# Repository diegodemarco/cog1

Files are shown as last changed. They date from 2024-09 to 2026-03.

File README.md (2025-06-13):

# cog1
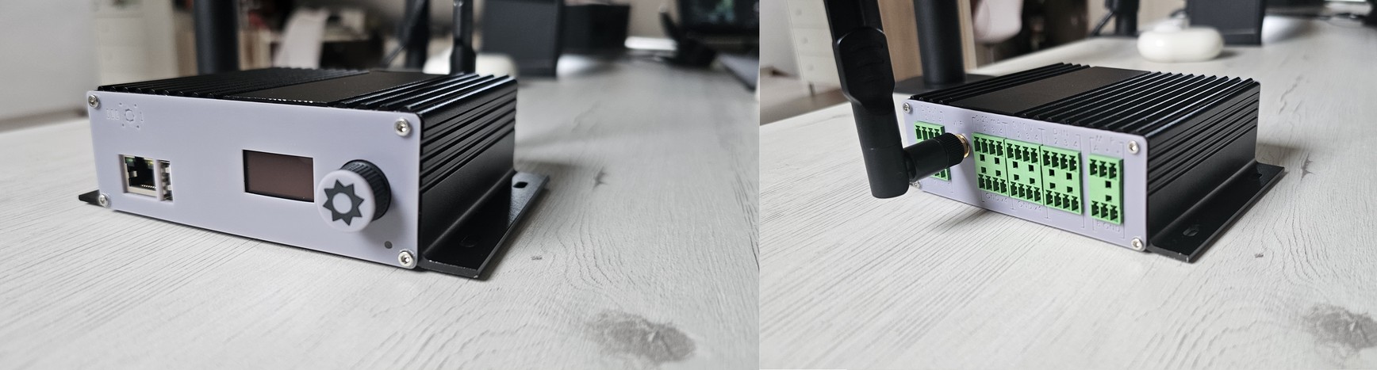
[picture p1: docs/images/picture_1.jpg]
cog1 front and back as built


## What is cog1?
cog1 is an open-source industrial IoT gateway (hardware and software) built as a motherboard hosting an [Orange Pi Zero 3](http://www.orangepi.org/html/hardWare/computerAndMicrocontrollers/details/Orange-Pi-Zero-3.html) linux SBC (Wiki [here](http://www.orangepi.org/orangepiwiki/index.php/Orange_Pi_Zero_3)).
- The motherboard was designed using [KiCad](https://www.kicad.org/).
- Its software uses the [.net core framework](https://dotnet.microsoft.com/) (currently at version 8) to provide the services running in the hardware, as well as the back-end web services for the UI.
- It also hosts the user interface (console), which is written  in [Angular](https://angular.dev/), based on the [Core-UI admin template](https://coreui.io/product/free-angular-admin-template/).
- In essence, it's a fully self-contained IoT gateway capable of interfacing with sensors and actuators directly, designed to process data, make local decisions, and communicate with external cloud services if needed.

### Features

#### Hardware
The cog1 platform currently supports:
- Powered by any DC supply from 12 to 24 VDC.
- Four digital inputs (isolated, using two [ISO 1212](https://www.ti.com/lit/ds/symlink/iso1212.pdf) chips from TI).
- Four digital outputs (relays, varistor-protected).
- Four analog voltage inputs (0-10 V, non-isolated), protected up to 48 VDC. The ADC is an [ADC128D818](https://www.ti.com/lit/ds/symlink/adc128d818.pdf) chip from TI.
- Four analog current inputs (0-20 mA, non isolated), protected up to 100 mA. Uses the same [ADC128D818](https://www.ti.com/lit/ds/symlink/adc128d818.pdf) chip as the voltage inputs.
- One RS-485 port (tested from 9600 to 115200 bauds). Support for Modbus RTU is already built on top of this.
- Battery-backed RTC.
- A simple but extensible user interface with a small OLED display and a rotary encoder + pushbutton.
- All connectivity inherited from the Orange Pi Zero 3 SBC
  - 1 Gb Ethernet
  - 2.4 + 5.8 GHz WiFi
  - Bluetooth 5
  - A front USB port (USB 2.0)

#### Software
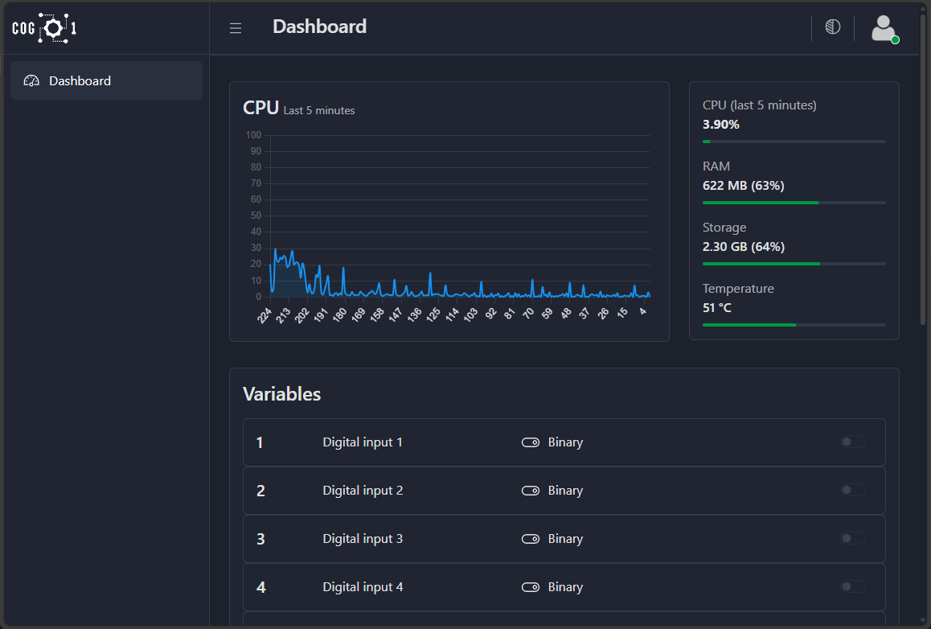
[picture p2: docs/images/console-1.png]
cog1 admin console

The current software is rather basic, but includes everything needed to fully test the hardware. Additionally, the software already has the correct "architecture", i.e. it is designed as a linux service file that can be started, stopped, etc., and communicates with the hardware through a low-level i/o library created with native code (plain old C).

The front-end (console) is written in Angular, based on the [Core-UI admin template](https://coreui.io/product/free-angular-admin-template/), and it communicates with the back-end via web-services, which are already integrated in such a way that creating new controllers/endpoints and consuming them from the front-end is really simple. 

The following features are already implemented:
- Internal variables are fully supported. These match the actual hardware of the cog1.
- External variables can be defined as well, based on Modbus registers.
- Both Modbus RTU and Modbus TCP are supported, allowing reading and writing the most common types of registers in a variety of data types.
- Variables can be defined to be "polled" automatically. For variables bound to Modbus registers, this means that the respective registers are polled via RTU or TCP as needed.
- Writeable variables can be controlled/modified from the dashboard.
- Writeable variables bound to Modbus registers also trigger the respective write operations through RTU or TCP, which can be done from the dashboard.

The plan is to continue developing the software so that it can:
- Provide data-extraction web services.
- Communicate with external cloud services via MQTT or any other protocol that could be relevant.
- Allow running javascript code using [Jint](https://github.com/sebastienros/jint) to make it possible to compute complex variables, do edge data-processing, etc.
- Update the console UI to allow further management of all avaible functionality, as it grows over time.

### Hardware
#### PCB
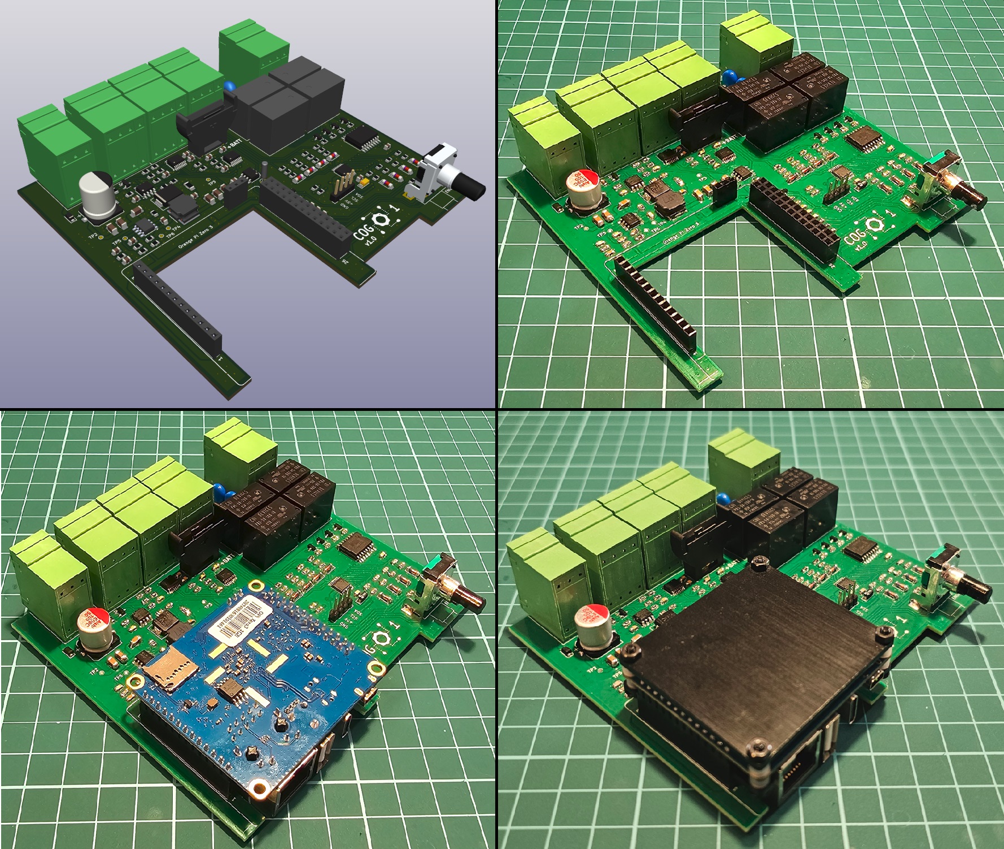
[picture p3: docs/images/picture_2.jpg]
cog1 PCB as rendered by KiCad


The PCB has been designed using KiCad. It contains everything needed, including a 3D render. All components can be hand-soldered, but a few (essentially the AOZ regulator, the ADC, and the digital input isolators) require a bit of skills, as they are SSOP components. 

All capacitors, resistors, etc. are 0805 or bigger, so they can be hand-soldered with little effort. The PCB contains all necessary headers to allow the Orange Pi Zero 3 to be plugged in, inverted.

All components can be found in the usual marketplaces (DigiKey, Mouser, etc.). I strongly advice not using unreliable (i.e. unrealistically cheap) sources for the components, especially the chips, as there is a large market of fake chips that either don't work, or even worse, work erratically.

#### Enclosure
The enclosure for the cog1 is a rather standard extruded-aluminum case, which can be found online for a few bucks. However, as a 3D printing enthusiast, I ended up designing and printing everything necessary to complete the enclosure:
- Front cover
- Back cover
- Knob

All designs, done in SolidWorks, are included in this project. I have printed everything with an Elegoo Mars 3 Pro (resin), and expect that all parts would print well on any resin 3D printer. I have not tried to print this on a filament printer, as I believe the quality would not be good enough. When printed in resin, all parts really look production-grade if the proper resin is used.

### Software
#### Main back-end code
The main code of the cog1 platform is a .net core application that contains all the necessary components (web services and general logic) to keep the cog1 working. The current version is relatively basic, and only contains those features needed to test the hardware. A web service is in place to provide basic status of the cog1, which is currently used to test the overall reliability of the hardware. All hardware functions have been tested with this software.

This is by far the area that needs the most effort, so that the cog1 can be turned into a fully-functional gateway.

#### Native back-end code
There are a few small portions of the software written in plan old C, and compiled directly in the SBC:
- A low-level i/o library that deals with digital and analog i/o, display, etc.
- A small "logo" application (configured as a service that starts early in the Linux boot process) to display the cog1 logo while the cog1 is booting.

Everything else is c#, so there's no low-level really in the c# code. 

#### Front-end code
The front-end (console) is written in Angular, based on the [Core-UI admin template](https://coreui.io/product/free-angular-admin-template/), and it communicates with the back-end via web-services, which are already integrated in such a way that creating new controllers/endpoints and consuming them from the front-end is really simple. While the functionality is relatively limited at the moment, the front-end contains all the necessary building-blocks to be extended easily:
- It communicates with the back-end via web-services, with proxies created using [swagger-typescript-api](https://github.com/acacode/swagger-typescript-api). This makes it very simple to create new controllers and endpoints in the back-end andthen use them in the front-end with full type-checking and code insight.
- It handles authentication with the back-end.
- It fully supports loading literals (in the language of the user) from the back-end, before the application starts.

## Getting started
### Building the hardware
The KiCad project included in the pcb folder contains everything needed to manufacture the pcb. For all prototypes, the pcb was ordered to PCBWay, and then all components were soldered manually. When soldering, I strongly advise mounting the switching power supply first, veryfying the 5V are steady and noiseless, and then mount everything else. This is to prevent blowing up anything if the switching power supply was not mounted correctly.

### Installing the software
I'll write a tutorial for this ASAP, but it's pretty straightforward.

## Current status
### What's done
### What's missing

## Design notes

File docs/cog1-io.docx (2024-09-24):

Outputs:

Function | GPIO / PIN | Comments

Front
Led – Heartbeat | 73 / 7
Encoder button | 75 / 12 (isr) | Internal pullup is used (4.7K ohms)
Encoder A | 72 / 15 (isr) | Internal pullup is used (4.7K ohms)
Encoder B | 231 / 19 (isr) | Internal pullup is used (4.7K ohms)
Conn - 485-A | none (UART.5)
Conn - 485-B | none (UART.5)
WiFi-antenna | none

Back
Power + | none
Power - | none
SSR1 + Common | none (PCF8574)
SSR2 + Common | none (PCF8574)
SSR3 + Common | none (PCF8574)
SSR4 + Common | none (PCF8574)
0-20-1 + Common | none (ADS1115-1)
0-20-2 + Common | none (ADS1115-1)
0-20-3 + Common | none (ADS1115-1)
0-20-4 + Common | none (ADS1115-1)
AN1 + Common | none (ADS1115-2)
AN2 + Common | none (ADS1115-2)
AN3 + Common | none (ADS1115-2)
AN4 + Common | none (ADS1115-2)
DI1 + Common | 74 / 26 (isr) | Internal pullup is used (4.7K ohms)
DI2 + Common | 233 / 24 (isr) | Internal pullup is used (4.7K ohms)
DI3 + Common | 230 / 23 (isr) | Internal pullup is used (4.7K ohms)
DI4 + Common | 232 / 21 (isr) | Internal pullup is used (4.7K ohms)

Connectors – Front

SMA (Wi-Fi)

Connectors – Back

Power + 485 (2x3)

TOP: VCC, 485A, 485B

Bottom: GND, GND, GND

0-20mA (2x 4)

TOP: AA1, AA2, AA3, AA4

Bottom: GND, GND, GND, GND

0-10V (2x 4)

TOP: AV1, AV2, AV3, AV4

Bottom: GND, GND, GND, GND

DIGITAL IN (2x 4)

TOP: DI1+, DI2+, DI3+, DI4+

Bottom: DI1-, DI2-, DI3-, DI4-

DIGITAL OUT (2x 4)

TOP: DO1A, DO2A, DO3A, DO4A

Bottom: DO1B, DO2B, DO3B, DO4B

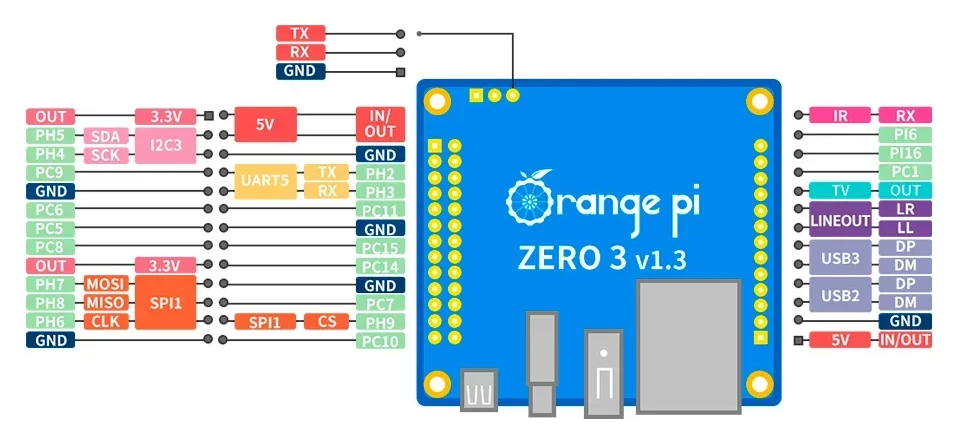
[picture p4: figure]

+------+-----+----------+--------+---+ H616 +---+--------+----------+-----+------+

| GPIO | wPi | Name | Mode | V | Physical | V | Mode | Name | wPi | GPIO |

+------+-----+----------+--------+---+----++----+---+--------+----------+-----+------+

| | | 3.3V | | | 1 || 2 | | | 5V | | |

| 229 | 0 | SDA.3 | ALT5 | 0 | 3 || 4 | | | 5V | | |

| 228 | 1 | SCL.3 | ALT5 | 0 | 5 || 6 | | | GND | | |

| 73 | 2 | PC9 | OUT | 0 | 7 || 8 | 0 | OFF | TXD.5 | 3 | 226 |

| | | GND | | | 9 || 10 | 0 | OFF | RXD.5 | 4 | 227 |

| 70 | 5 | PC6 | OUT | 0 | 11 || 12 | 0 | OFF | PC11 | 6 | 75 |

| 69 | 7 | PC5 | ALT5 | 0 | 13 || 14 | | | GND | | |

| 72 | 8 | PC8 | OFF | 0 | 15 || 16 | 0 | OFF | PC15 | 9 | 79 |

| | | 3.3V | | | 17 || 18 | 0 | OFF | PC14 | 10 | 78 |

| 231 | 11 | MOSI.1 | OFF | 0 | 19 || 20 | | | GND | | |

| 232 | 12 | MISO.1 | OFF | 0 | 21 || 22 | 0 | OFF | PC7 | 13 | 71 |

| 230 | 14 | SCLK.1 | OFF | 0 | 23 || 24 | 0 | OFF | CE.1 | 15 | 233 |

| | | GND | | | 25 || 26 | 0 | OFF | PC10 | 16 | 74 |

| 65 | 17 | PC1 | OFF | 0 | 27 || 28 | | | | | |

| 272 | 18 | PI16 | ALT2 | 0 | 29 || 30 | | | | | |

| 262 | 19 | PI6 | OFF | 0 | 31 || 32 | | | | | |

| 234 | 20 | PH10 | ALT3 | 0 | 33 || 34 | | | | | |

+------+-----+----------+--------+---+----++----+---+--------+----------+-----+------+

| GPIO | wPi | Name | Mode | V | Physical | V | Mode | Name | wPi | GPIO |

+------+-----+----------+--------+---+ H616 +---+--------+----------+-----+------+

Display screens

123456789012345678901

0 STATUS

1 ---------------------

2 Date 2024-07-23 23:59

3 WiFi 192.192.192.192

4 Eth 192.192.192.192

5 Temp 44ºC/92ºF

6 CPU (1 min) 1.8%

7 Firmware 1.0.0.0

123456789012345678901

0 D-IO IN OUT

1 ---------------------

2

3 1 (--) (--)

4 2 (--) (--)

5 3 (--) (--)

6 4 (--) (--)

7

123456789012345678901

0 A-IN V mA

1 ---------------------

2

3 1 0.00 0.00

4 2 0.00 0.00

5 3 0.00 0.00

6 4 0.00 0.00

7

123456789012345678901

0 Wi-Fi

1 ---------------------

2 Status

3 SSID Los De Marco

4 IP 192.192.192.192

5 Band 8153 MHz

6 RSSI -58 dBm

7

123456789012345678901

0 Ethernet

1 ---------------------

2 IP 192.192.192.192

3

4

5

6

7

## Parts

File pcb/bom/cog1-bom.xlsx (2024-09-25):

Id | Designator | Footprint | Quantity | Designation
34 | R58 | R_0805_2012Metric | 1 | 1.2K 1%
7 | C21,C4,C20,C5,C14,C3,C1,C18,C6 | C_0805_2012Metric | 9 | 100nF
19 | R7,R3,R2 | R_0805_2012Metric | 3 | 100R
20 | C7 | CP_Elec_10x12.6 | 1 | 100uF 50V
4 | R43,R46,R8,R47,R1,R39,R37,R4,R36,R13,R38 | R_0805_2012Metric | 11 | 10K
16 | R41,R31,R28,R10,R34 | R_0805_2012Metric | 5 | 10K 1%
21 | C26,C23,C24,C25,C16 | C_0805_2012Metric | 5 | 10nF
35 | R59 | R_0815_2038Metric_Pad1.20x4.05mm_HandSolder | 1 | 10R 1/2W
13 | C10,C9,C8 | C_1206_3216Metric_Pad1.33x1.80mm_HandSolder | 3 | 10uF 50V
26 | C2 | C_0805_2012Metric | 1 | 10uF 6.3V
22 | R57,R44,R45 | R_0805_2012Metric | 3 | 1K
29 | C22 | CP_EIA-3216-10_Kemet-I_Pad1.58x1.35mm_HandSolder | 1 | 1uF
32 | R56 | R_0805_2012Metric | 1 | 255R
25 | R33,R27,R30,R40 | R_0805_2012Metric | 4 | 255R 1%
3 | R21,R18,R24,R17 | R_0805_2012Metric | 4 | 30.1K 1%
33 | Y1 | Crystal_C26-LF_D2.1mm_L6.5mm_Vertical | 1 | 32.768 KHz
42 | C19 | C_0805_2012Metric | 1 | 330pF 50V
2 | R14,R22,R25,R15,R19 | R_0805_2012Metric | 5 | 330R
14 | R11 | R_0805_2012Metric | 1 | 47K
27 | C11,C13,C12 | C_1206_3216Metric_Pad1.33x1.80mm_HandSolder | 3 | 47uF 10V
43 | R9 | R_0805_2012Metric | 1 | 52K 1%
1 | R49,R48,R5,R6 | R_0805_2012Metric | 4 | 560R
41 | C15 | C_0805_2012Metric | 1 | 56pF
47 | C17 | C_0805_2012Metric | 1 | 820pF
40 | R12 | R_0805_2012Metric | 1 | 82K
12 | R29,R32,R26,R23,R35,R16,R20,R42 | R_0805_2012Metric | 8 | 9.53K 1%
46 | U12 | TSSOP-16_4.4x5mm_P0.65mm | 1 | ADC128D818
37 | U5 | AOZ1284PI | 1 | AOZ1284PI
24 | D3 | D_SMC | 1 | B560C-13-F
18 | RV1,RV2,RV3,RV4 | RV_Disc_D7mm_W4.5mm_P5mm | 4 | B72207S0301K103
9 | Q2,Q3,Q4,Q1,Q5 | SOT-23 | 5 | BC807
39 | BATT1 | BH-50B-1 | 1 | BH-50B-1
28 | J1 | PinHeader_1x04_P2.54mm_Vertical | 1 | Conn_01x04_Pin
49 | LED1 | LED_0805_2012Metric_Pad1.15x1.40mm_HandSolder | 1 | INL-3AW30
36 | U2,U4 | SSOP-16_3.9x4.9mm_P0.635mm | 2 | ISO1212
48 | D14,D2,D15,D13 | D_MiniMELF | 4 | LL4148
38 | U10 | SOIC-8_3.9x4.9mm_P1.27mm | 1 | MAX13487E
6 | U$1 | OPI-ZERO-3 | 1 | OPI-ZERO-3
45 | U3 | SOIC-16W_7.5x10.3mm_P1.27mm | 1 | PCA8574D
44 | U1 | SOIC-8_3.9x4.9mm_P1.27mm | 1 | PCF8523T
17 | ENC1 | BOURNS_PEC_HORZ_20 | 1 | PEC12R-2120F-S0012
5 | K1,K3,K4,K2 | PR5-5V-200-1A | 4 | PR5-5V-200-1A
30 | D12 | SOT-23-3 | 1 | SM712
10 | L1 | Bourns_SRN8040TA | 1 | SRN8040TA-4R7M
11 | D1 | D_SOD-123F | 1 | SS2040LL_R1_00001
23 | TP5,TP2,TP3,TP6,TP1,TP4 | TestPoint_Pad_D1.0mm | 6 | TestPoint
31 | CN1 | VL0631510000G | 1 | VL0631510000G
15 | CN3,CN4,CN2,CN5 | VL0831510000G | 4 | VL0831510000G
8 | D11,D7,D9,D8,D4,D10,D6,D5 | D_MiniMELF | 8 | ZMM3.0

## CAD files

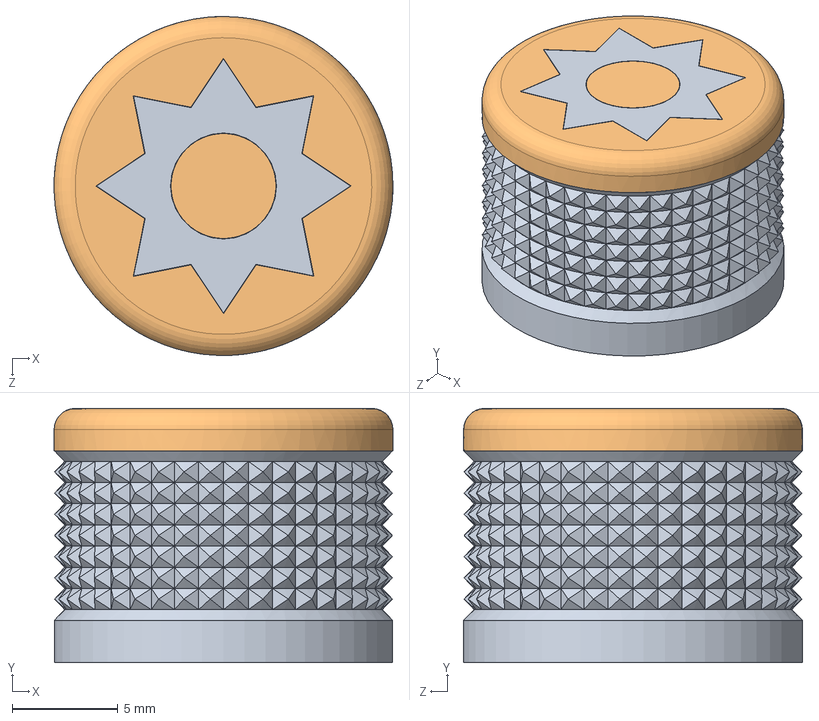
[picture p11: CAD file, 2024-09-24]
enclosure/knob_asembly.SLDASM
16.0 x 12.0 x 16.0 mm
knob
knob-insert

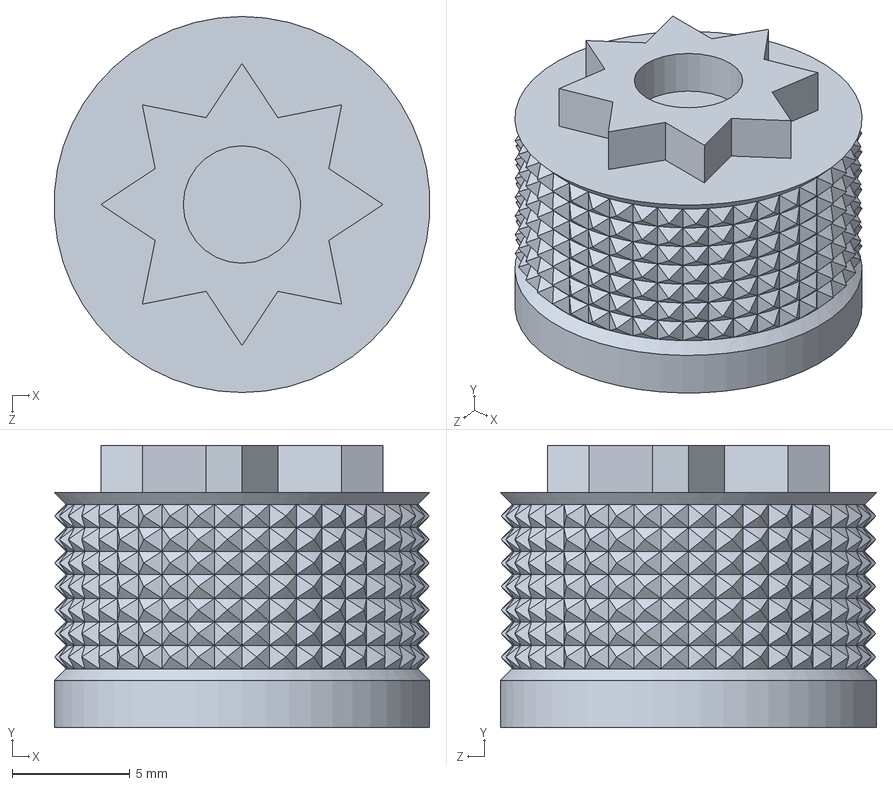
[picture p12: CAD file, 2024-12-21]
enclosure/knob.SLDPRT
16.0 x 12.0 x 16.0 mm

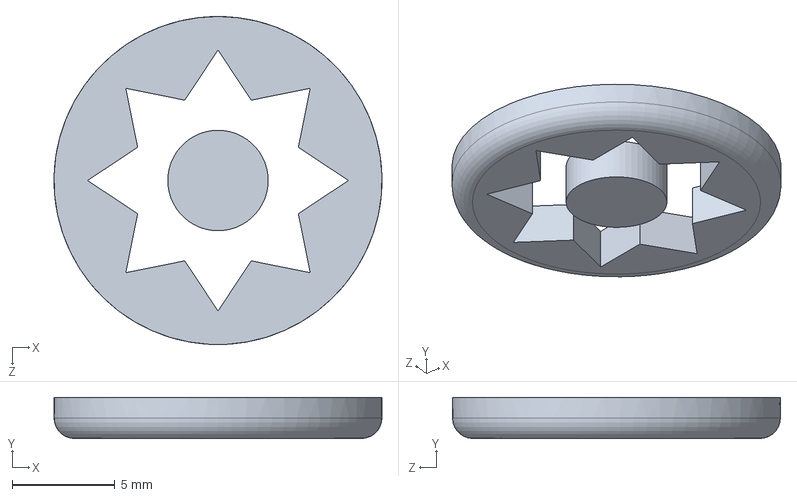
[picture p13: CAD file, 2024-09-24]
enclosure/knob-insert.SLDPRT
16.0 x 2.00 x 16.0 mm

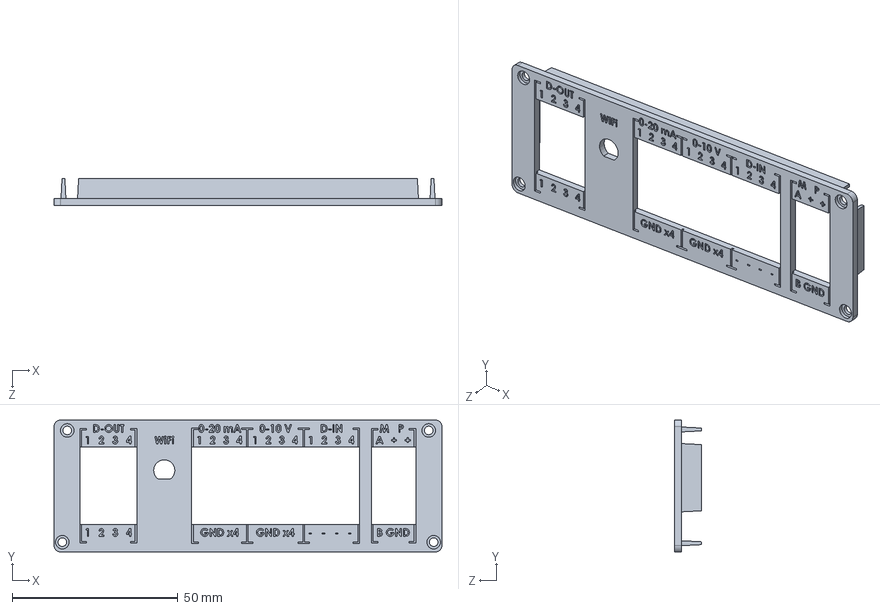
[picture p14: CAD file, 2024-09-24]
enclosure/cog-1-back-lid.SLDPRT
117.0 x 39.8 x 8.00 mm

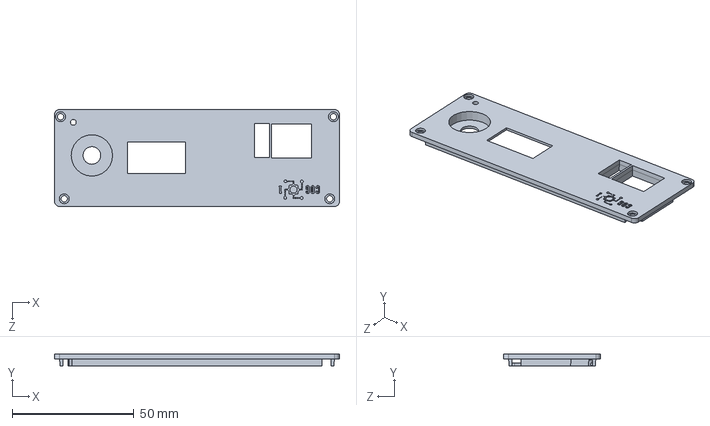
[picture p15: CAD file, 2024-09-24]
enclosure/cog-1-front-lid.SLDPRT
117.0 x 5.00 x 39.8 mm

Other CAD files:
enclosure/cog-1-back-lid.STL
enclosure/cog-1-front-lid.STL
enclosure/knob-insert.STL
enclosure/knob.STL

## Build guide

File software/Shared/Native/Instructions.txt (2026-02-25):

Basic configuration (requres keyboard and monitor)
--------------------------------------------------
- Connect a monitor and a keyboard
- Boot and wait for the login prompt.
- At the prompt, run "sudo orangepi-config". Press any key to ignore the fact that there's no active network connection.
- In the menu, select "Network", press [Enter], then select "WiFi", and press [Enter] again.
- Select the WiFi network you want to connect to, and press [Enter].
- Type the password and [Enter]. Wait until the connection completes.
- Exit by typing escape multiple times until you're back at the command prompt.
- Type "sudo ifconfig" and verify that you're connected to the network. You should see an IP address assigned to the WiFi adapter. This is the IP you'll use to connect through ssh.
- Before powering off, connect to the Orange pi via ssh from another computer, just to be sure.
- At the command prompt, type "sudo shutdown now". You can do this from the Orange pi's keyboard or from the ssh session on the other computer.
- The Orange pi will power off.
- Remove keyboard and monitor. You don't need them anymore.

Additional configuration via ssh
--------------------------------
- Connect to the Orange pi via ssh. User is "root", password is "orangepi".
- Change the password:
  - type "passwd", then your new password (for instance "cog1pass"), and then type it again to verify.
- Disable user "orangepi"
  - type "usermod -L -e 1 orangepi"
  - Change tty1 so that it does not use the orangepi user. To do this, edit file "/lib/systemd/system/getty@.service.d/override.conf":
    - type "vi /lib/systemd/system/getty@.service.d/override.conf"
    - change "orangepi" to "root"
	- save and quit
  - Change the serial terminal so that it does not use the orangepi user. To do this, edit file "/lib/systemd/system/serial-getty@.service.d/override.conf"
    - type "vi /lib/systemd/system/serial-getty@.service.d/override.conf"
    - change "orangepi" to "root"
	- save and quit
- Apply the latest updates to the OS:
  - type "apt-get update". This will look for updates for all installed software packages. Wait for the process to finish.
  - type "apt-get upgrade" to apply whatever updates were found. Wait for the process to finish.
- Install cog1 dependencies:
  - type "apt-get install libgpiod-dev"
  - type "apt-get install zip"
  - type "apt-get install eject"
- Mount the cog1 folder
  - type "mkdir ~/cog1-dev".
  - type "sudo mount -t cifs //[machine or ip]/[Shared folder] ~/cog1-dev -o username=[username],password=[password]
- Install the cog1 software
  - type "cd ~/cog1-dev/native" to make sure you're in your home folder
  - type "./install-all.sh"
- Enable all necessary hardware overlays
  - type "orangepi-config"
  - Choose "System"
  - Choose "Hardware"
  - Use the space bar to select "pcf-8523", "ph-i2c3", and "ph-uart5". This will enable the i2c-3 controller, use the pcf-8523 as the rtc, and enable the serial uart 5.
  - Choose "Save"
  - When asked to reboot, choose "Reboot" so that the changes are applied.
- Wait for the reboot, and reconnect via ssh.
- Remove user "orangepi", which we disabled before.
  - type "userdel orangepi"
- Mount the cog1-dev folder again.
  - type "cd ~/cog1-dev" 
  - type "./run.sh" to run the cog1 application manually and to check everything is fine.
  - Stop by pressing ctrl+c
  - Type "./up.sh". This will install cog1 locally and start it as a service.
- Optional: configure fsck to check the root file system on every boot.
  - edit file "/boot/boot.cmd":
    - type "vi /boot/boot.cmd"
	- edit the line that starts with "setenv bootargs"
	- at the end of that line, add the following: "fsck.mode=force fsck.repair=yes" (leave a space before this and whatever existed before).
	- go to the end of the file, and you will see a comment that indicates the command to run in order to compile this file.
	- for example, in my image, this command is "mkimage -C none -A arm -T script -d /boot/boot.cmd /boot/boot.scr"
	- copy the command, save the file, quit, and run that command.
- At this point, you can reboot by typing "reboot now". On the OLED display, you should see the cog1 logo, and then the screensaver with the current time.
- That's it, you're good to go.

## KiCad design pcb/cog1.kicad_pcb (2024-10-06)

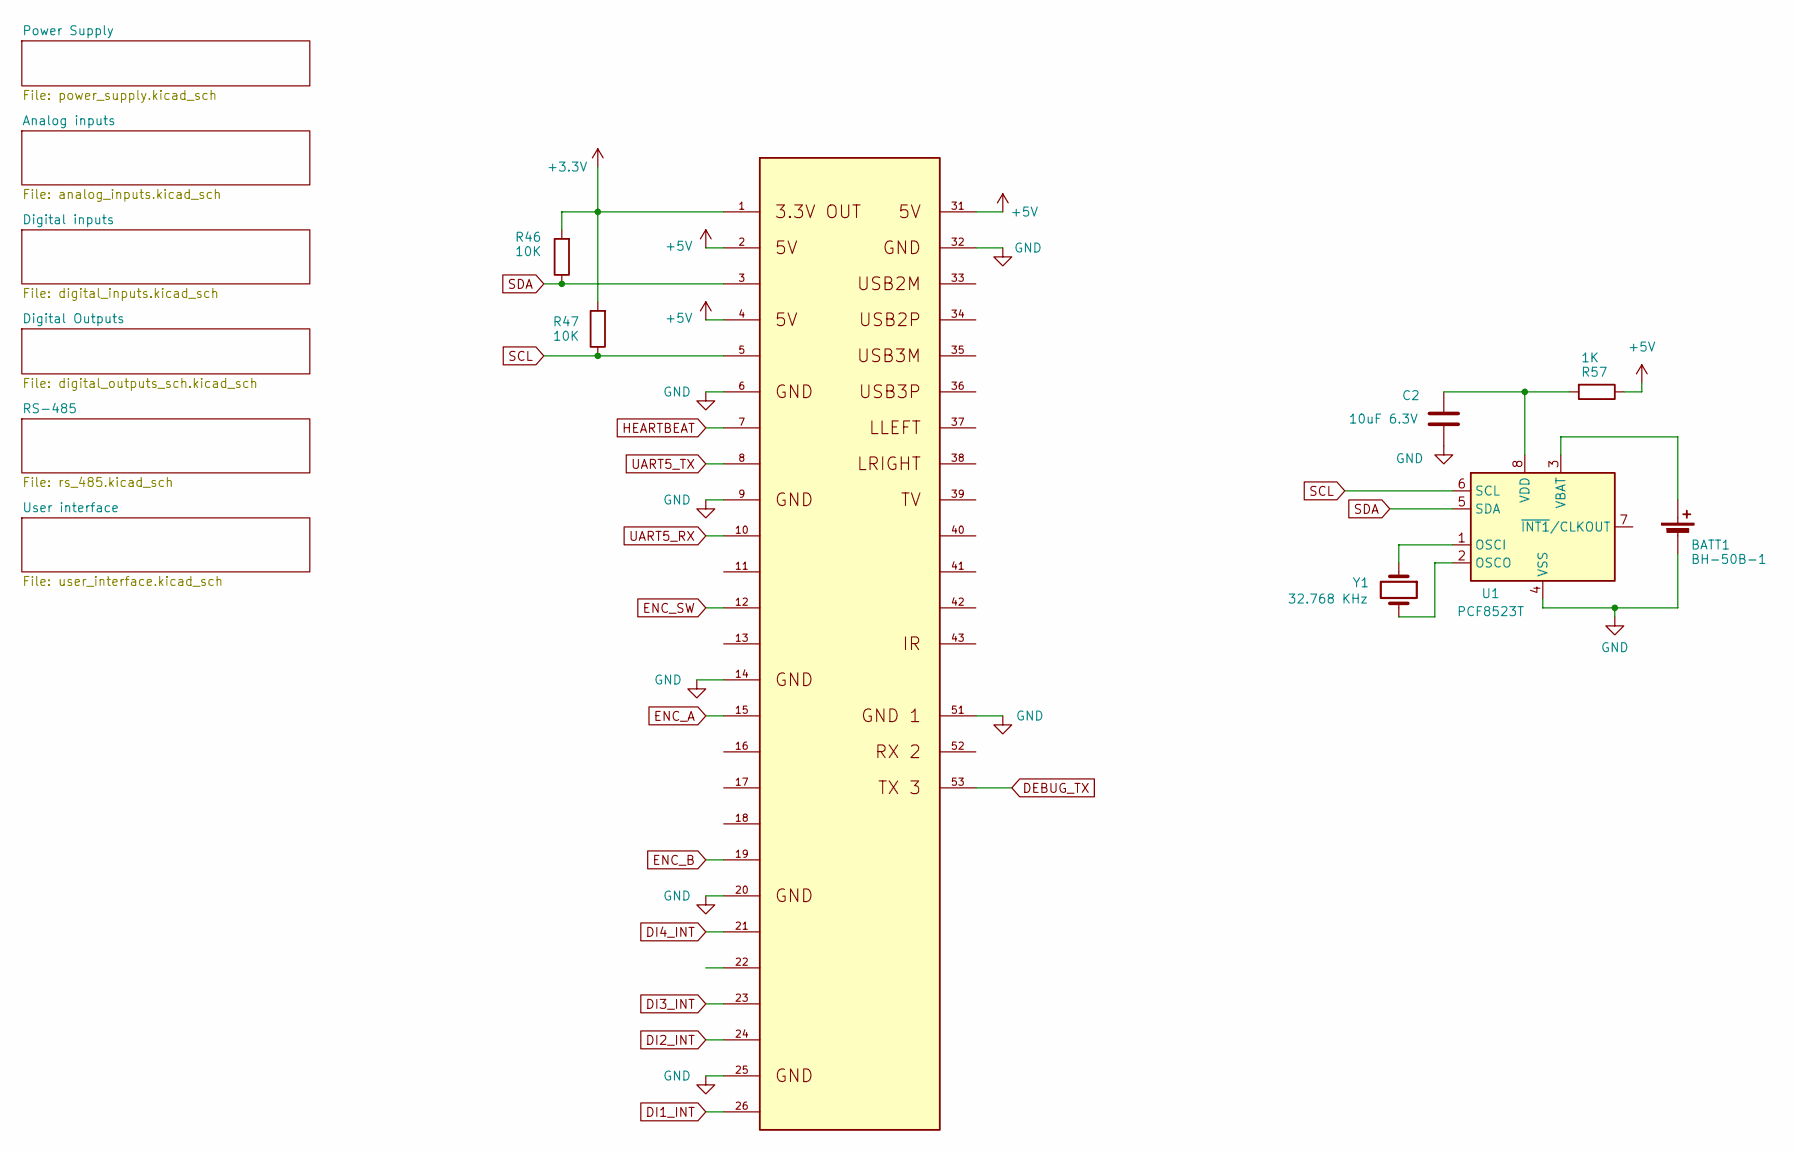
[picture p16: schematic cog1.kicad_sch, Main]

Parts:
BATT1: BH-50B-1
C2: 10uF 6.3V; C_0805_2012Metric
R46, R47: 10K; R_0805_2012Metric
R57: 1K; R_0805_2012Metric
U1: PCF8523T; SOIC-8_3.9x4.9mm_P1.27mm
U$1: OPI-ZERO-3
Y1: 32.768 KHz; Crystal_C26-LF_D2.1mm_L6.5mm_Vertical

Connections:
+3.3V: R46.2, R47.2, U$1.1; also elsewhere on the board
+5V: R57.1, U$1.2, U$1.4, U$1.31; also elsewhere on the board
DEBUG_TX: U$1.53; also elsewhere on the board
DI1_INT: U$1.26; also elsewhere on the board
DI2_INT: U$1.24; also elsewhere on the board
DI3_INT: U$1.23; also elsewhere on the board
DI4_INT: U$1.21; also elsewhere on the board
ENC_A: U$1.15; also elsewhere on the board
ENC_B: U$1.19; also elsewhere on the board
ENC_SW: U$1.12; also elsewhere on the board
GND: BATT1.2 (-), C2.1, U1.4 (VSS), U$1.6, U$1.9, U$1.14, U$1.20, U$1.25, U$1.32, U$1.51; also elsewhere on the board
HEARTBEAT: U$1.7; also elsewhere on the board
unnamed: BATT1.1 (+), U1.3 (VBAT)
unnamed: U1.1 (OSCI), Y1.1
unnamed: U1.2 (OSCO), Y1.2
unnamed: C2.2, R57.2, U1.8 (VDD)
SCL: R47.1, U1.6 (SCL), U$1.5; also elsewhere on the board
SDA: R46.1, U1.5 (SDA), U$1.3; also elsewhere on the board
UART5_RX: U$1.10; also elsewhere on the board
UART5_TX: U$1.8; also elsewhere on the board

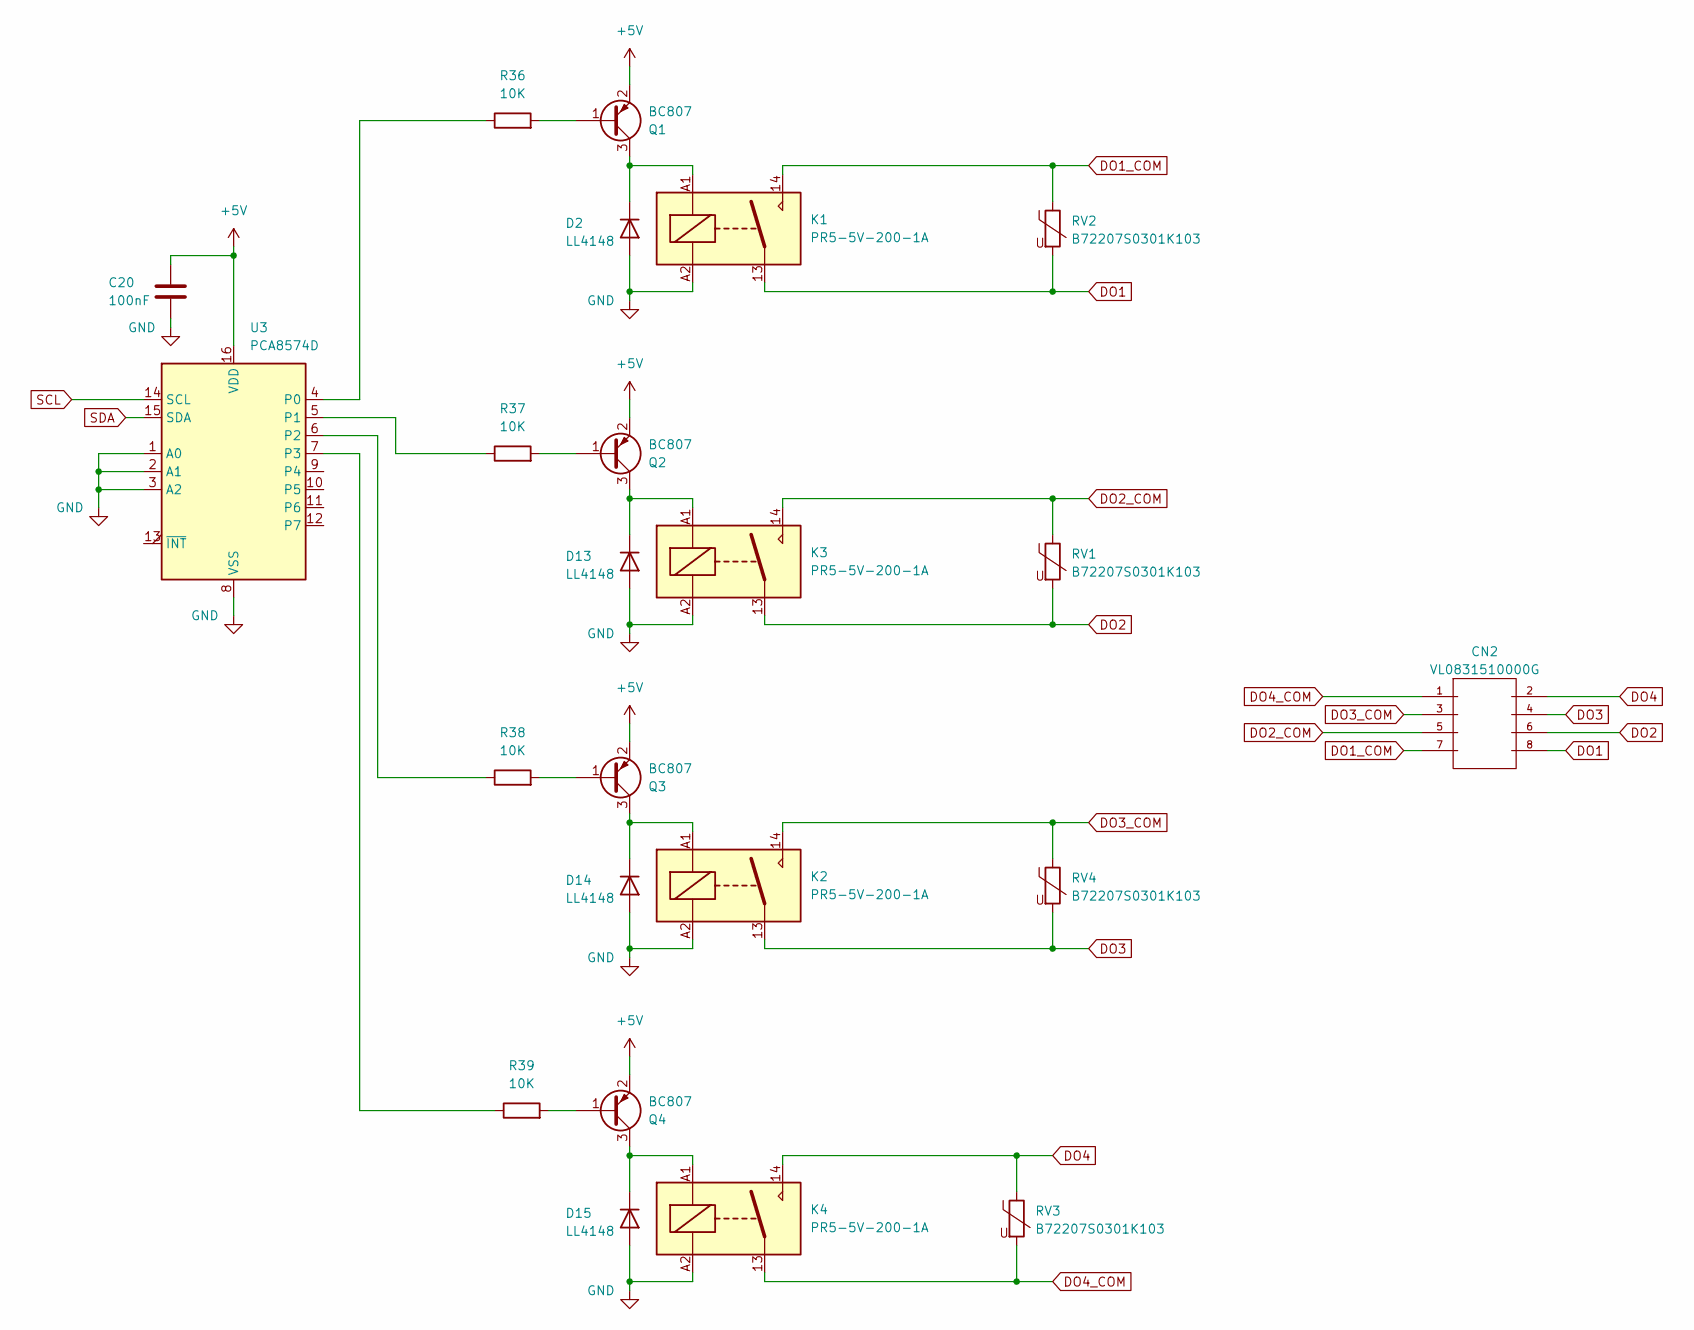
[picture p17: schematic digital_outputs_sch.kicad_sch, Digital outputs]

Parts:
C20: 100nF; C_0805_2012Metric
CN2: VL0831510000G
D2, D13, D14, D15: LL4148; D_MiniMELF
K1, K2, K3, K4: PR5-5V-200-1A
Q1, Q2, Q3, Q4: BC807; SOT-23
R36, R37, R38, R39: 10K; R_0805_2012Metric
RV1, RV2, RV3, RV4: B72207S0301K103; RV_Disc_D7mm_W4.5mm_P5mm
U3: PCA8574D; SOIC-16W_7.5x10.3mm_P1.27mm

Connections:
+5V: C20.1, Q1.2 (E), Q2.2 (E), Q3.2 (E), Q4.2 (E), U3.16 (VDD); also elsewhere on the board
DO1: CN2.8, K1.13, RV2.2
DO1_COM: CN2.7, K1.14, RV2.1
DO2: CN2.6, K3.13, RV1.2
DO2_COM: CN2.5, K3.14, RV1.1
DO3: CN2.4, K2.13, RV4.2
DO3_COM: CN2.3, K2.14, RV4.1
DO4: CN2.2, K4.14, RV3.1
DO4_COM: CN2.1, K4.13, RV3.2
GND: C20.2, D2.2 (A), D13.2 (A), D14.2 (A), D15.2 (A), K1.A2, K2.A2, K3.A2, K4.A2, U3.1 (A0), U3.2 (A1), U3.3 (A2), U3.8 (VSS); also elsewhere on the board
unnamed: D2.1 (K), K1.A1, Q1.3 (C)
unnamed: D13.1 (K), K3.A1, Q2.3 (C)
unnamed: D14.1 (K), K2.A1, Q3.3 (C)
unnamed: D15.1 (K), K4.A1, Q4.3 (C)
unnamed: Q1.1 (B), R36.2
unnamed: Q2.1 (B), R37.2
unnamed: Q3.1 (B), R38.2
unnamed: Q4.1 (B), R39.2
unnamed: R36.1, U3.4 (P0)
unnamed: R37.1, U3.5 (P1)
unnamed: R38.1, U3.6 (P2)
unnamed: R39.1, U3.7 (P3)
SCL: U3.14 (SCL); also elsewhere on the board
SDA: U3.15 (SDA); also elsewhere on the board

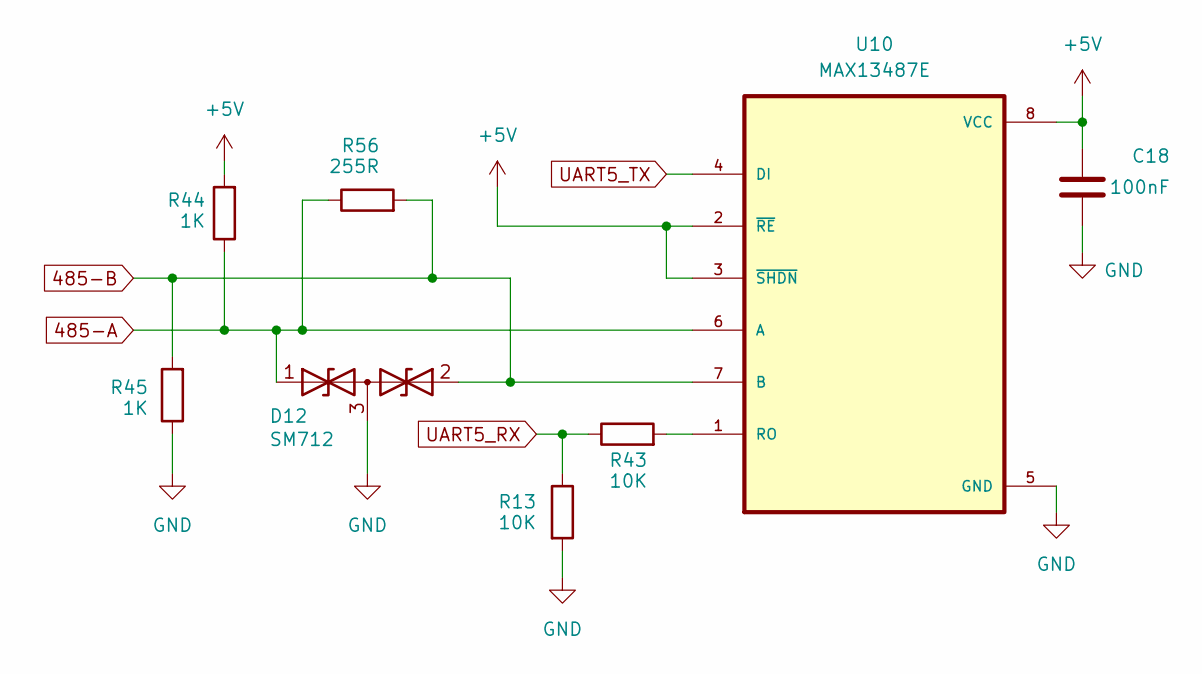
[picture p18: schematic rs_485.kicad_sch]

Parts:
C18: 100nF; C_0805_2012Metric
D12: SM712; SOT-23-3
R13, R43: 10K; R_0805_2012Metric
R44, R45: 1K; R_0805_2012Metric
R56: 255R; R_0805_2012Metric
U10: MAX13487E; SOIC-8_3.9x4.9mm_P1.27mm

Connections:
485-A: D12.1 (A1), R44.1, R56.1, U10.6 (A); also elsewhere on the board
485-B: D12.2 (A2), R45.2, R56.2, U10.7 (B); also elsewhere on the board
+5V: C18.2, R44.2, U10.2 (~RE), U10.3 (~SHDN), U10.8 (VCC); also elsewhere on the board
GND: C18.1, D12.3 (common), R13.2, R45.1, U10.5 (GND); also elsewhere on the board
unnamed: R43.2, U10.1 (RO)
UART5_RX: R13.1, R43.1; also elsewhere on the board
UART5_TX: U10.4 (DI); also elsewhere on the board

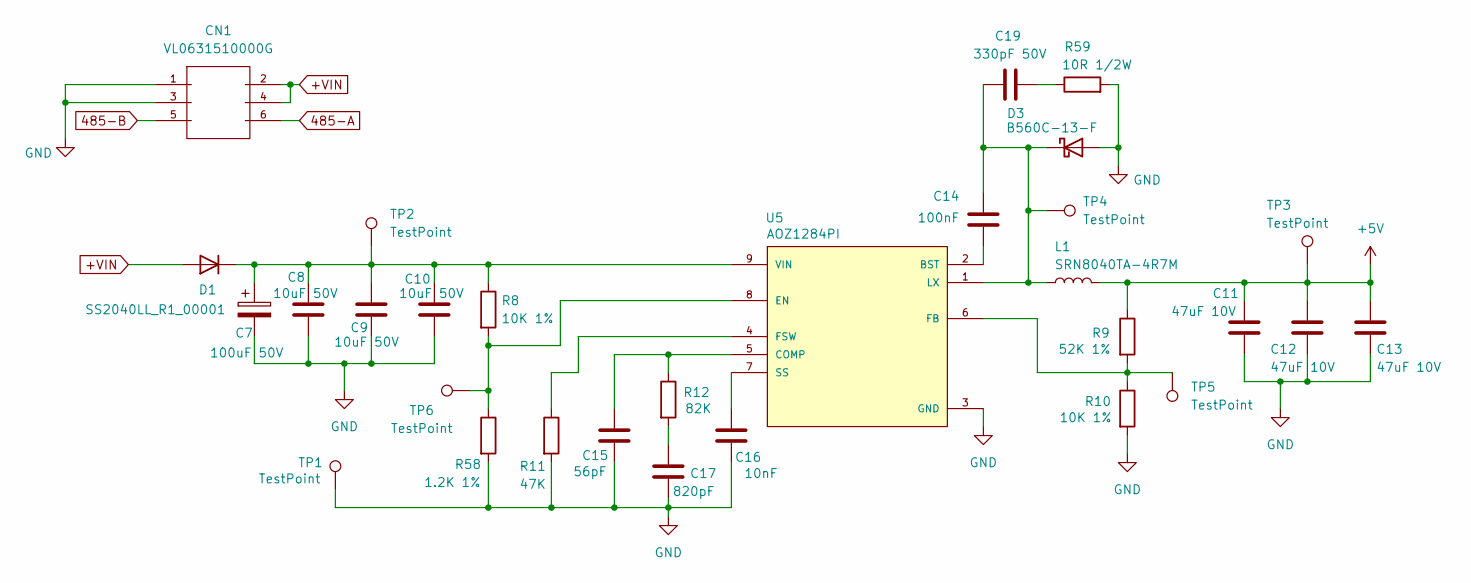
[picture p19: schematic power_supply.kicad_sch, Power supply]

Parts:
C7: 100uF 50V; CP_Elec_10x12.6
C8, C9, C10: 10uF 50V; C_1206_3216Metric_Pad1.33x1.80mm_HandSolder
C11, C12, C13: 47uF 10V; C_1206_3216Metric_Pad1.33x1.80mm_HandSolder
C14: 100nF; C_0805_2012Metric
C15: 56pF; C_0805_2012Metric
C16: 10nF; C_0805_2012Metric
C17: 820pF; C_0805_2012Metric
C19: 330pF 50V; C_0805_2012Metric
CN1: VL0631510000G
D1: SS2040LL_R1_00001; D_SOD-123F
D3: B560C-13-F; D_SMC
L1: SRN8040TA-4R7M; Bourns_SRN8040TA
R8, R10: 10K 1%; R_0805_2012Metric
R9: 52K 1%; R_0805_2012Metric
R11: 47K; R_0805_2012Metric
R12: 82K; R_0805_2012Metric
R58: 1.2K 1%; R_0805_2012Metric
R59: 10R 1/2W; R_1206_3216Metric_Pad1.30x1.75mm_HandSolder
TP1, TP2, TP3, TP4, TP5, TP6: TestPoint; TestPoint_Pad_D1.0mm
U5: AOZ1284PI

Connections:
485-A: CN1.6; also elsewhere on the board
485-B: CN1.5; also elsewhere on the board
+5V: C11.1, C12.1, C13.1, L1.2, R9.1, TP3.1; also elsewhere on the board
+VIN: CN1.2, CN1.4, D1.2 (A)
GND: C7.2, C8.2, C9.2, C10.2, C11.2, C12.2, C13.2, C15.1, C16.1, C17.1, CN1.1, CN1.3, D3.2 (A), R10.2, R11.2, R58.2, R59.2, TP1.1, U5.3 (GND); also elsewhere on the board
unnamed: C17.2, R12.2
unnamed: C19.1, R59.1
unnamed: C7.1, C8.1, C9.1, C10.1, D1.1 (K), R8.1, TP2.1, U5.9 (VIN)
unnamed: C14.2, C19.2, D3.1 (K), L1.1, TP4.1, U5.1 (LX)
unnamed: C14.1, U5.2 (BST)
unnamed: C15.2, R12.1, U5.5 (COMP)
unnamed: R8.2, R58.1, TP6.1, U5.8 (EN)
unnamed: R9.2, R10.1, TP5.1, U5.6 (FB)
unnamed: R11.1, U5.4 (FSW)
unnamed: C16.2, U5.7 (SS)

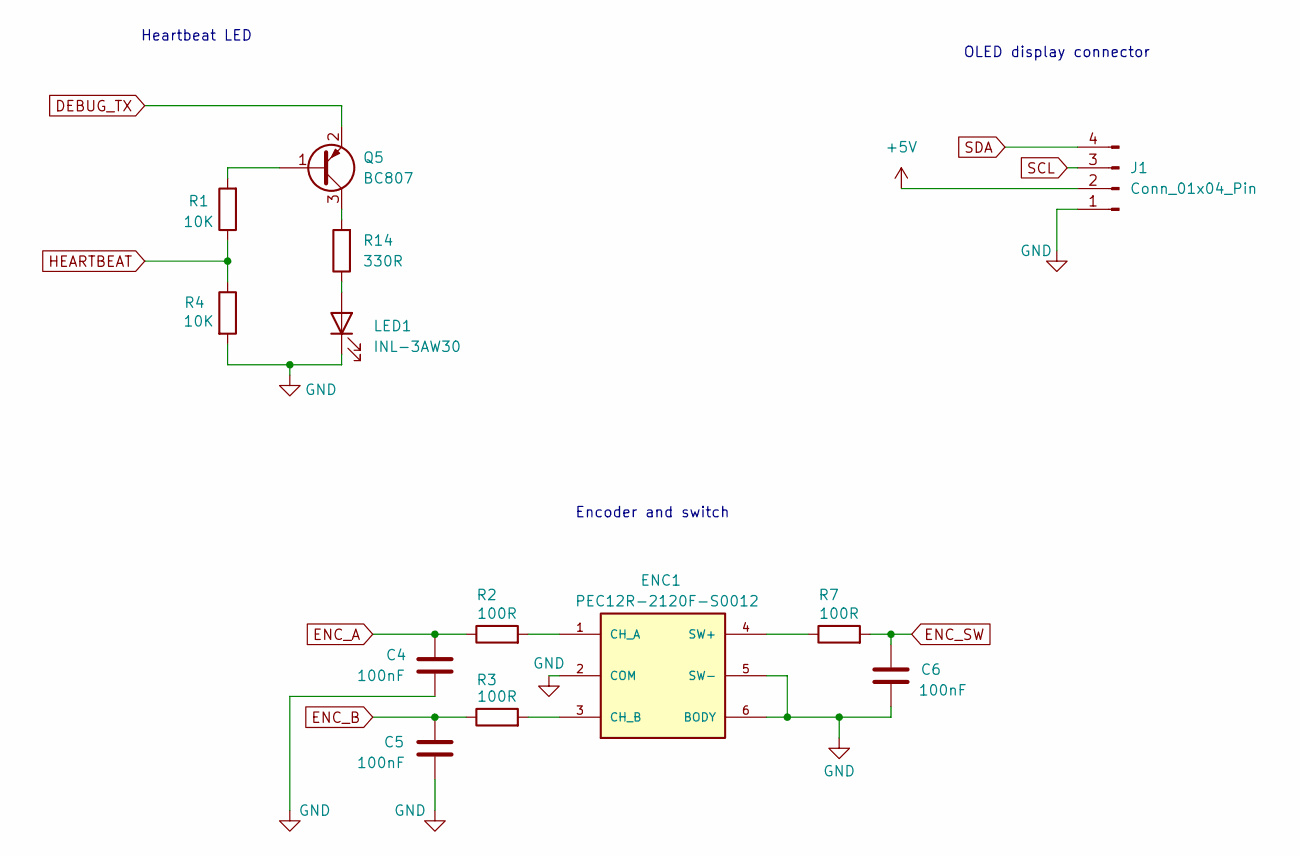
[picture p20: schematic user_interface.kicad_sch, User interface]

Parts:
C4, C5, C6: 100nF; C_0805_2012Metric
ENC1: PEC12R-2120F-S0012; BOURNS_PEC_HORZ_20
J1: Conn_01x04_Pin; PinHeader_1x04_P2.54mm_Vertical
LED1: INL-3AW30; LED_0805_2012Metric_Pad1.15x1.40mm_HandSolder
Q5: BC807; SOT-23
R1, R4: 10K; R_0805_2012Metric
R2, R3, R7: 100R; R_0805_2012Metric
R14: 330R; R_0805_2012Metric

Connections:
+5V: J1.2; also elsewhere on the board
DEBUG_TX: Q5.2 (E); also elsewhere on the board
ENC_A: C4.1, R2.1; also elsewhere on the board
ENC_B: C5.1, R3.1; also elsewhere on the board
ENC_SW: C6.1, R7.2; also elsewhere on the board
GND: C4.2, C5.2, C6.2, ENC1.2 (COM), ENC1.5 (SW-), ENC1.6 (BODY), J1.1, LED1.1 (K), R4.2; also elsewhere on the board
HEARTBEAT: R1.1, R4.1; also elsewhere on the board
unnamed: ENC1.1 (CH_A), R2.2
unnamed: ENC1.3 (CH_B), R3.2
unnamed: ENC1.4 (SW+), R7.1
unnamed: LED1.2 (A), R14.1
unnamed: Q5.1 (B), R1.2
unnamed: Q5.3 (C), R14.2
SCL: J1.3; also elsewhere on the board
SDA: J1.4; also elsewhere on the board

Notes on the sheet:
Encoder and switch
Heartbeat LED
OLED display connector

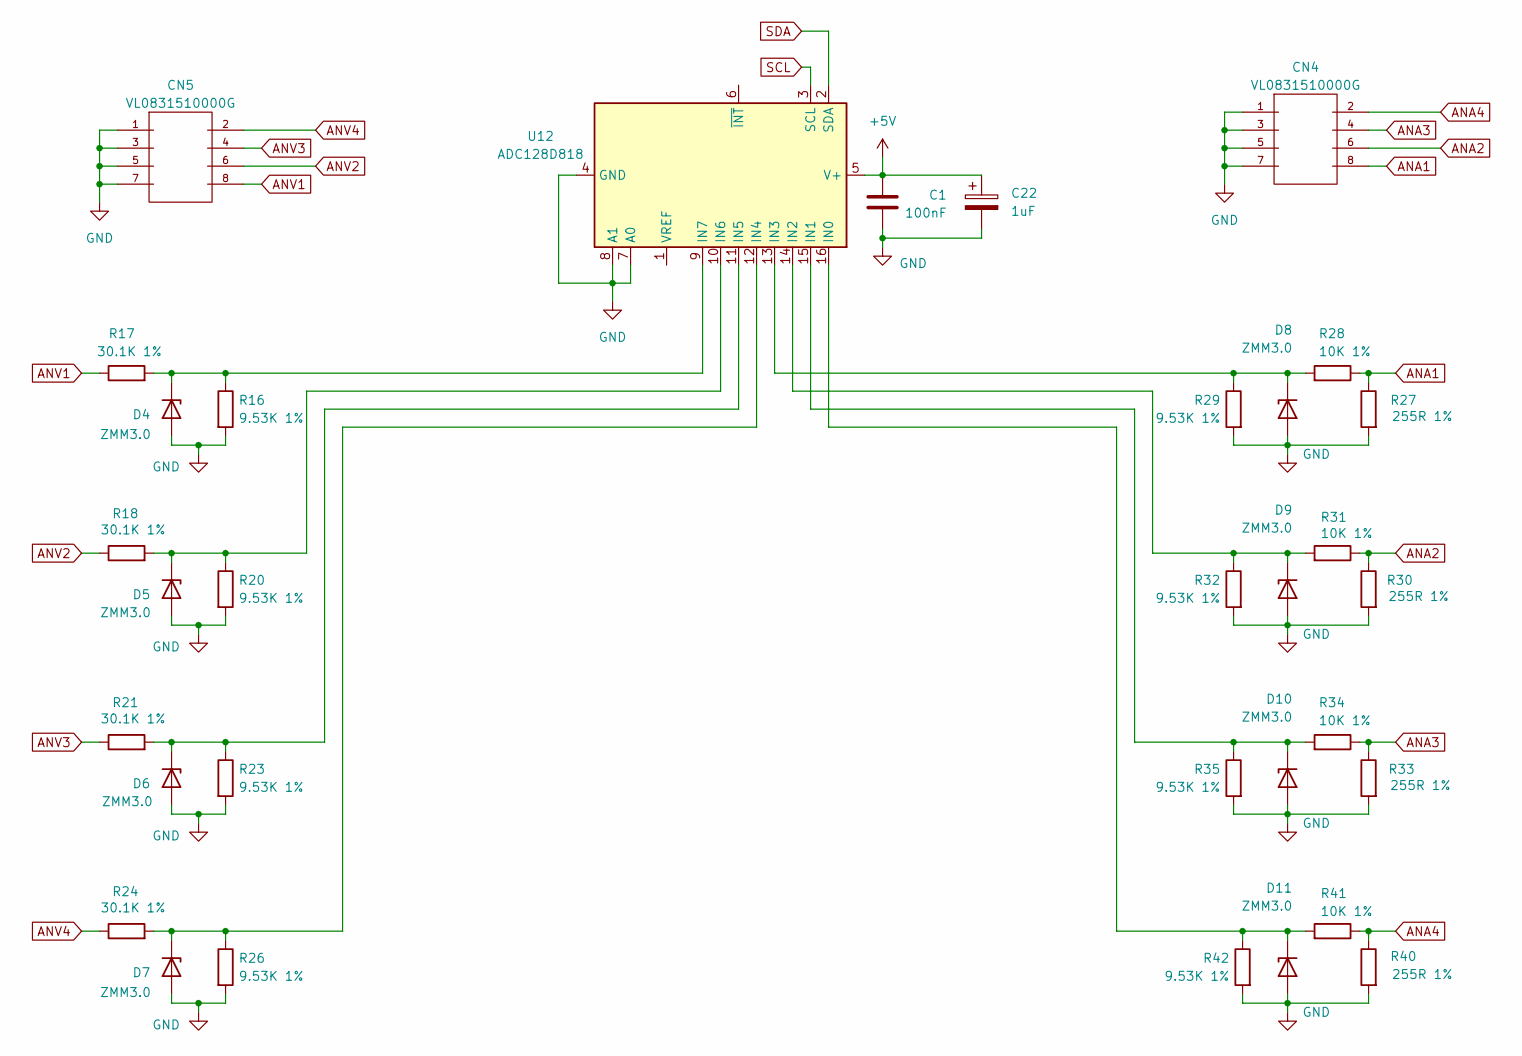
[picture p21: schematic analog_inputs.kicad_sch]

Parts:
C1: 100nF; C_0805_2012Metric
C22: 1uF; CP_EIA-3216-10_Kemet-I_Pad1.58x1.35mm_HandSolder
CN4, CN5: VL0831510000G
D4, D5, D6, D7, D8, D9, D10, D11: ZMM3.0; D_MiniMELF
R16, R20, R23, R26, R29, R32, R35, R42: 9.53K 1%; R_0805_2012Metric
R17, R18, R21, R24: 30.1K 1%; R_0805_2012Metric
R27, R30, R33, R40: 255R 1%; R_0805_2012Metric
R28, R31, R34, R41: 10K 1%; R_0805_2012Metric
U12: ADC128D818; TSSOP-16_4.4x5mm_P0.65mm

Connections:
+5V: C1.1, C22.1, U12.5 (V+); also elsewhere on the board
ANA1: CN4.8, R27.1, R28.1
ANA2: CN4.6, R30.1, R31.1
ANA3: CN4.4, R33.1, R34.1
ANA4: CN4.2, R40.1, R41.1
ANV1: CN5.8, R17.1
ANV2: CN5.6, R18.1
ANV3: CN5.4, R21.1
ANV4: CN5.2, R24.1
GND: C1.2, C22.2, CN4.1, CN4.3, CN4.5, CN4.7, CN5.1, CN5.3, CN5.5, CN5.7, D4.2 (A), D5.2 (A), D6.2 (A), D7.2 (A), D8.2 (A), D9.2 (A), D10.2 (A), D11.2 (A), R16.2, R20.2, R23.2, R26.2, R27.2, R29.2, R30.2, R32.2, R33.2, R35.2, R40.2, R42.2, U12.4 (GND), U12.7 (A0), U12.8 (A1); also elsewhere on the board
unnamed: D4.1 (K), R16.1, R17.2, U12.9 (IN7)
unnamed: D5.1 (K), R18.2, R20.1, U12.10 (IN6)
unnamed: D6.1 (K), R21.2, R23.1, U12.11 (IN5)
unnamed: D7.1 (K), R24.2, R26.1, U12.12 (IN4)
unnamed: D8.1 (K), R28.2, R29.1, U12.13 (IN3)
unnamed: D9.1 (K), R31.2, R32.1, U12.14 (IN2)
unnamed: D10.1 (K), R34.2, R35.1, U12.15 (IN1)
unnamed: D11.1 (K), R41.2, R42.1, U12.16 (IN0)
SCL: U12.3 (SCL); also elsewhere on the board
SDA: U12.2 (SDA); also elsewhere on the board

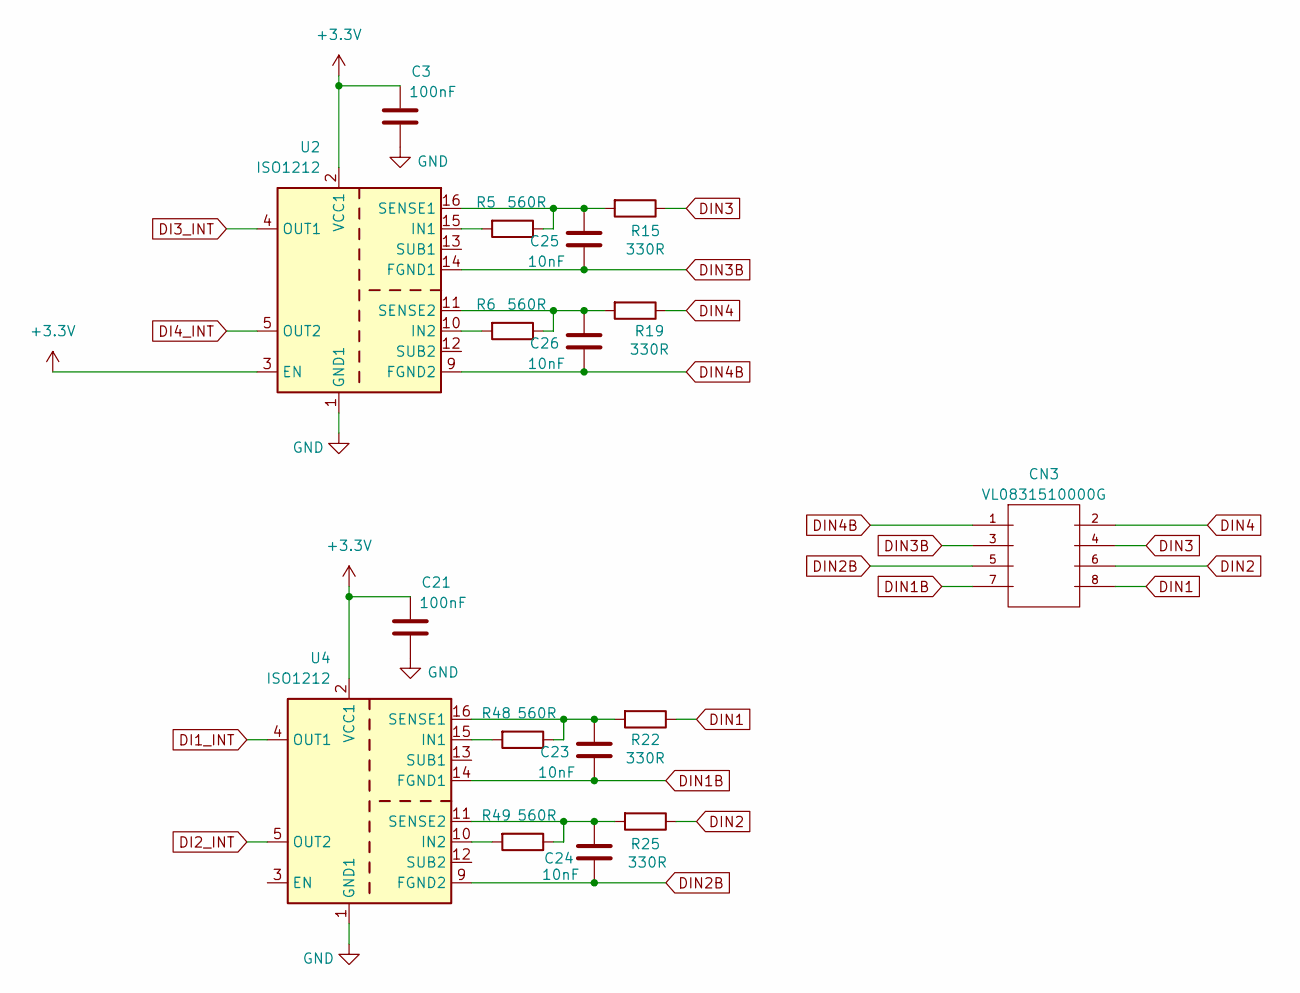
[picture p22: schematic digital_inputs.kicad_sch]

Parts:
C3, C21: 100nF; C_0805_2012Metric
C23, C24, C25, C26: 10nF; C_0805_2012Metric
CN3: VL0831510000G
R5, R6, R48, R49: 560R; R_0805_2012Metric
R15, R19, R22, R25: 330R; R_0805_2012Metric
U2, U4: ISO1212; SSOP-16_3.9x4.9mm_P0.635mm

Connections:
+3.3V: C3.1, C21.1, U2.2 (VCC1), U2.3 (EN), U4.2 (VCC1); also elsewhere on the board
DI1_INT: U4.4 (OUT1); also elsewhere on the board
DI2_INT: U4.5 (OUT2); also elsewhere on the board
DI3_INT: U2.4 (OUT1); also elsewhere on the board
DI4_INT: U2.5 (OUT2); also elsewhere on the board
DIN1: CN3.8, R22.1
DIN1B: C23.2, CN3.7, U4.14 (FGND1)
DIN2: CN3.6, R25.1
DIN2B: C24.2, CN3.5, U4.9 (FGND2)
DIN3: CN3.4, R15.1
DIN3B: C25.2, CN3.3, U2.14 (FGND1)
DIN4: CN3.2, R19.1
DIN4B: C26.2, CN3.1, U2.9 (FGND2)
GND: C3.2, C21.2, U2.1 (GND1), U2.8 (GND1), U4.1 (GND1), U4.8 (GND1); also elsewhere on the board
unnamed: R5.2, U2.15 (IN1)
unnamed: R6.2, U2.10 (IN2)
unnamed: C25.1, R5.1, R15.2, U2.16 (SENSE1)
unnamed: C26.1, R6.1, R19.2, U2.11 (SENSE2)
unnamed: R48.2, U4.15 (IN1)
unnamed: R49.2, U4.10 (IN2)
unnamed: C23.1, R22.2, R48.1, U4.16 (SENSE1)
unnamed: C24.1, R25.2, R49.1, U4.11 (SENSE2)

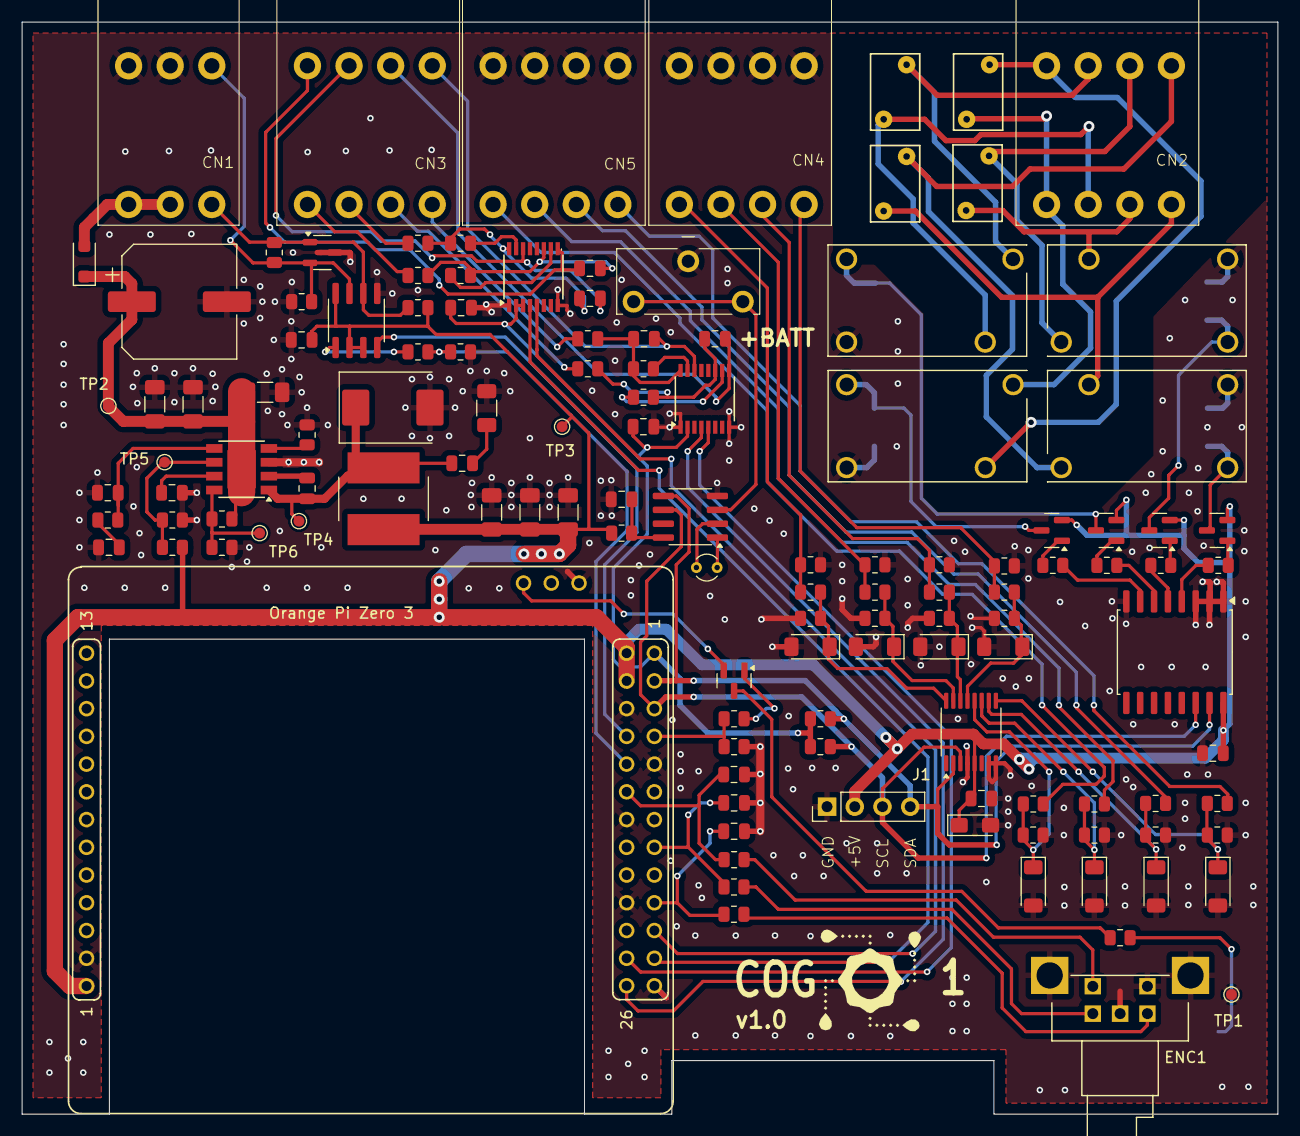
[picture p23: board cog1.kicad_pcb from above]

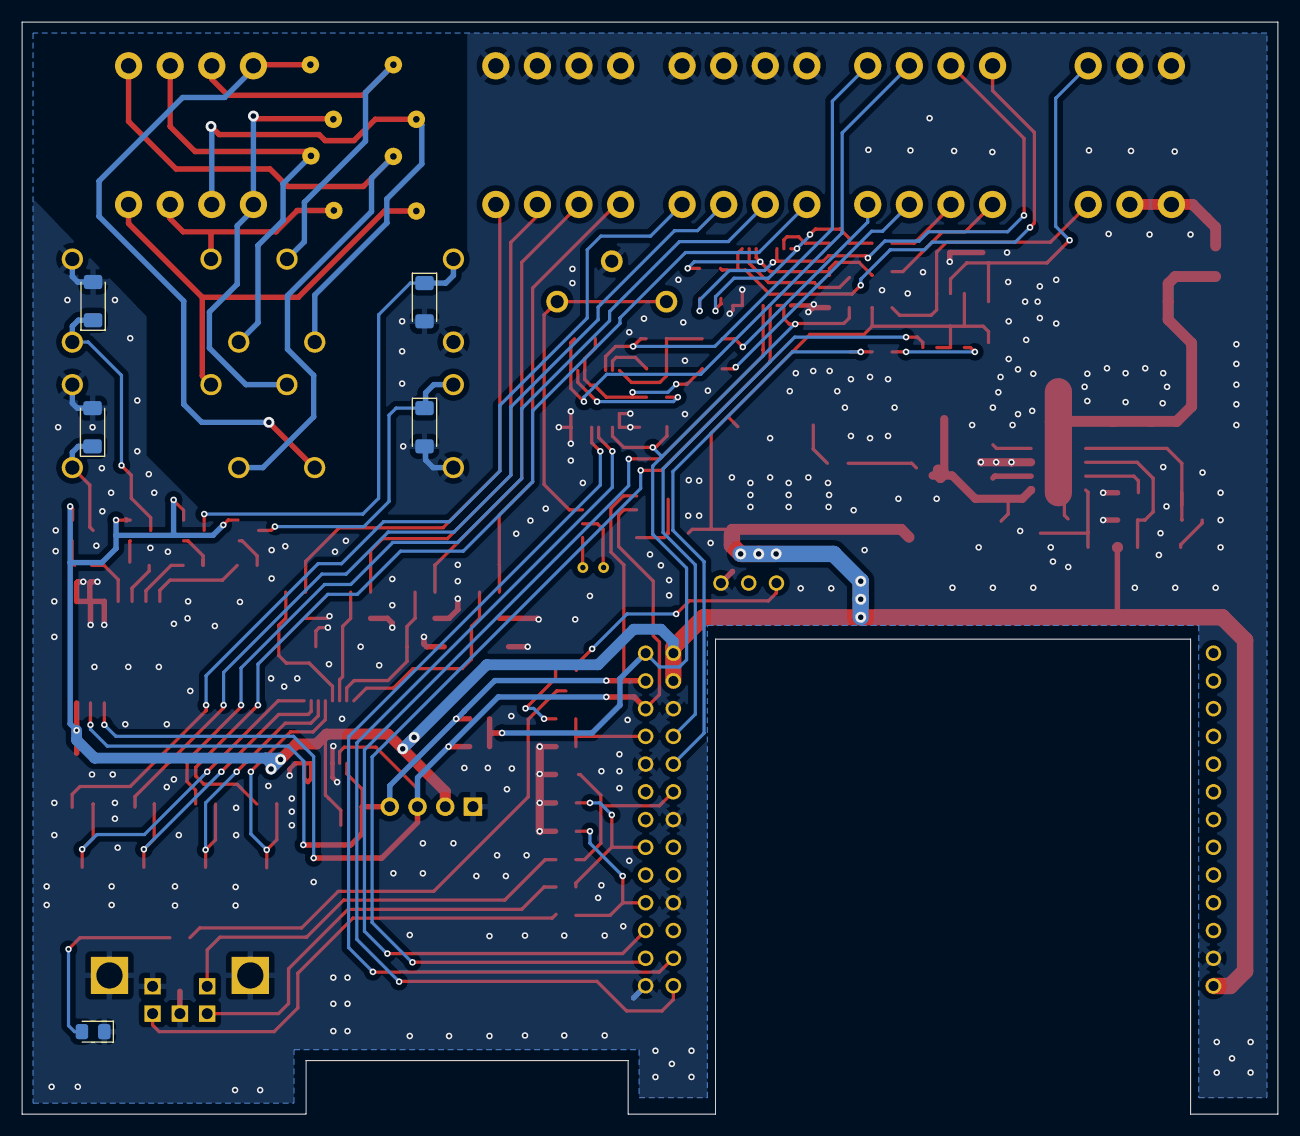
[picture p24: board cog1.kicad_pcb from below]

Board: 2 copper layers, 115.0 x 100.0 mm, 132 parts (5 on the bottom side), 92 nets.

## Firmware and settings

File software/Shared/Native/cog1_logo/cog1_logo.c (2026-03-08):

#include <stdio.h>
#include <time.h>
#include <errno.h> 
#include <fcntl.h>
#include <unistd.h>
#include <sys/ioctl.h>
#include "../include/cog1_oled.h"
#include "../include/cog1_i2c.h"
#include "logo.h"

int i2c_fd = 0;
const char *i2c_device = "/dev/i2c-3";

int main()
{
	int i2c_fd = i2c_open(i2c_device);
    if (i2c_fd < 0)
    {
		printf("Error opening I2C device: %d\n", i2c_fd);
		return -1;
    }
	
	int r = oled_config(i2c_fd, 64, 128, 1);
	if (r > 0)
	{
		r = oled_set_xy(i2c_fd, 0, 0);
		if (r > 0)
		{
			r = oled_show_bitmap(i2c_fd, oled_logo, sizeof(oled_logo));
			if (r <= 0) 
			{
				printf("oled_show_bitmap error: %d\n", r);
			}
		}
		else 
		{
			printf("oled_clear error: %d\n", r);
		}
	}
	else
	{
		printf("oled_default_config error: %d\n", r);
	}
	
	return 0;
}

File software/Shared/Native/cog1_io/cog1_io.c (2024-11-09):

#include <stdio.h>
#include <time.h>
#include <errno.h> 
#include <fcntl.h>
#include <stdint.h>
#include <unistd.h>
#include <gpiod.h>
#include <pthread.h>
#include "../include/cog1_i2c.h"
#include "../include/cog1_oled.h"

#define io_expander_address_1 			0x38
#define io_expander_address_2 			0x20
#define adc_address						0x1d

// Number of input pins monitored via IRQ
#define IRQ_PIN_COUNT					7

// Encoder pins
#define PIN_ENCODER_A					72
#define PIN_ENCODER_B					231
#define PIN_ENCODER_BUTTON				75

// Heartbeat LED pin
#define PIN_HEARTBEAT					73

// Digital input pins
#define PIN_DI_1						74
#define PIN_DI_2						233
#define PIN_DI_3						230
#define PIN_DI_4						232

// IO events
#define IO_EVENT_ENCODER_CW				1
#define IO_EVENT_ENCODER_CCW			2
#define IO_EVENT_ENCODER_SW_ACTIVE		4
#define IO_EVENT_ENCODER_SW_INACTIVE	8
#define IO_EVENT_DI1_ACTIVE				16
#define IO_EVENT_DI1_INACTIVE			32
#define IO_EVENT_DI2_ACTIVE				64
#define IO_EVENT_DI2_INACTIVE			128
#define IO_EVENT_DI3_ACTIVE				256
#define IO_EVENT_DI3_INACTIVE			512
#define IO_EVENT_DI4_ACTIVE				1024
#define IO_EVENT_DI4_INACTIVE			2048

const char *i2c_device = "/dev/i2c-3";

int oled_fd = 0;
int expander_fd = 0;
int adc_fd = 0;

pthread_t _h_di_thread;
unsigned char io_expander_address = 0;
char *_IO_CHIP_NAME = "gpiochip0";
char *_IO_CONSUMER = "cog1";
void (*_di_isr)(int event_bitmap) = NULL;
unsigned int _io_line_di_offsets[IRQ_PIN_COUNT] = { PIN_ENCODER_A, PIN_ENCODER_B, PIN_ENCODER_BUTTON, PIN_DI_1, PIN_DI_2, PIN_DI_3, PIN_DI_4 };

struct gpiod_chip *_h_io_chip = NULL;
struct gpiod_line_bulk _h_io_line_bulk_di;
struct gpiod_line *_h_line_heartbeat;

int heartbeat(int x)
{
	return gpiod_line_set_value(_h_line_heartbeat, x ? 0 : 1);		// Low value = ON
}

int do_control( int do_bitmap )
{
	// P7 in the port expander must be kept low, to signal that the
	// expander has been initialized. This is useful to understand
	// upon startup, if this is a reboot/restart, or if power was
	// lost.
	unsigned char portValue = 0b01111111;			// "active" bits should be zero
	if (do_bitmap & 1) portValue &= 0b11111110;		// DO1 = expander P0
	if (do_bitmap & 2) portValue &= 0b11111101;		// DO2 = expander P1
	if (do_bitmap & 4) portValue &= 0b11111011;		// DO3 = expander P2
	if (do_bitmap & 8) portValue &= 0b11110111;		// DO4 = expander P3
	int result = i2c_write_byte(expander_fd, io_expander_address, portValue);
	if (result != 1)
		printf("Error %d setting port expander output to %d\n", result, portValue);
	return (result == 1);
}

int adc_read_channel(unsigned char reg_address, int *value)
{
	unsigned char buffer[2];
	int r = i2c_read_bytes_register(adc_fd, adc_address, reg_address, buffer, 2);
	if (r < 0) return r;
	
	*value = ((int)(buffer[0]) * 0x100) + (int)(buffer[1]);
	*value = *value >> 4;
	
	return r;
}

int adc_read( int *c1, int *c2, int *c3, int *c4, int *c5, int *c6, int *c7, int *c8 )
{
	int r        = adc_read_channel(0x20, c1);
	if (r > 0) r = adc_read_channel(0x21, c2);
	if (r > 0) r = adc_read_channel(0x22, c3);
	if (r > 0) r = adc_read_channel(0x23, c4);
	if (r > 0) r = adc_read_channel(0x24, c5);
	if (r > 0) r = adc_read_channel(0x25, c6);
	if (r > 0) r = adc_read_channel(0x26, c7);
	if (r > 0) r = adc_read_channel(0x27, c8);
	if (r <= 0)
	{
		printf("Error reading adc: %d\n", r);
	}
	return (r > 0);
}

int display_init()
{
	int r = oled_config(oled_fd, 128, 64, 1);
	if (r <= 0) 
	{
		printf("Error initializing OLED display: %d\n", r);
	}
	return (r > 0);
}

void display_clear()
{
	oled_clear(oled_fd);
}

void display_goto_xy(int x, int y)
{
	oled_set_xy(oled_fd, x, y);
}

void display_draw_bitmap(int x, int y, const unsigned char *data, int data_len)
{
	oled_set_xy(oled_fd, x, y);
	oled_show_bitmap(oled_fd, data, data_len);
}

void *_di_poll_thread(void *args)
{
	static int prev_a = 0;
	static int prev_b = 0;
	static int prev_sw = 0;
	static int prev_di1 = 0;
	static int prev_di2 = 0;
	static int prev_di3 = 0;
	static int prev_di4 = 0;
	static int values[IRQ_PIN_COUNT];
	const struct timespec ts = {1, 0};
	static struct gpiod_line_bulk event_lines;
	static struct gpiod_line_event dummy_event;

	for (;;)
	{
		if (gpiod_line_event_wait_bulk(&_h_io_line_bulk_di, &ts, &event_lines) > 0)
		{
			// Read events to reset the wait state of the respective lines
			for (int i = 0; i < gpiod_line_bulk_num_lines(&event_lines); i++)
				gpiod_line_event_read(gpiod_line_bulk_get_line(&event_lines, i), &dummy_event);

			int flags = 0;

			// Read pin values
			if (gpiod_line_get_value_bulk(&_h_io_line_bulk_di, values) == 0)
			{
				// Encoder-related pins
				if (values[0] != prev_a || values[1] != prev_b || values[2] != prev_sw) 
				{
					//printf("Encoder: A=%d, B=%d, SW=%d\n", values[0], values[1], values[2]);

					// Add ISR events if the knob was turned
					if (values[0] && values[1])
					{
						if (prev_a && !prev_b)
						{
							flags |= IO_EVENT_ENCODER_CW;
						} else if (!prev_a && prev_b)
						{
							flags |= IO_EVENT_ENCODER_CCW;
						}
					}
					prev_a = values[0];
					prev_b = values[1];
									
					// Add ISR events if the button changed
					if (values[2] != prev_sw)
						flags |= (values[2] ? IO_EVENT_ENCODER_SW_INACTIVE : IO_EVENT_ENCODER_SW_ACTIVE);
					prev_sw = values[2];
				}
				
				// Digital-input-related pins
				if (values[3] != prev_di1 || values[4] != prev_di2 || values[5] != prev_di3 || values[6] != prev_di4)
				{
					//printf("DI: 1=%d, 2=%d, 3=%d, 4=%d\n", values[3], values[4], values[5], values[6]);

					if (values[3] != prev_di1)
						flags |= (values[3] ? IO_EVENT_DI1_ACTIVE : IO_EVENT_DI1_INACTIVE);
					if (values[4] != prev_di2)
						flags |= (values[4] ? IO_EVENT_DI2_ACTIVE : IO_EVENT_DI2_INACTIVE);
					if (values[5] != prev_di3)
						flags |= (values[5] ? IO_EVENT_DI3_ACTIVE : IO_EVENT_DI3_INACTIVE);
					if (values[6] != prev_di4)
						flags |= (values[6] ? IO_EVENT_DI4_ACTIVE : IO_EVENT_DI4_INACTIVE);

					prev_di1 = values[3];
					prev_di2 = values[4];
					prev_di3 = values[5];
					prev_di4 = values[6];
				}

			}

			// Call the ISR if there are any events
			if (flags > 0)
			{
				//printf("Calling ISR(%d)\n", flags);
				_di_isr(flags);
			}
			
		}
	}
}

int di_read(int *bitmap)
{
	*bitmap = 0;
	int values[IRQ_PIN_COUNT];
	if (gpiod_line_get_value_bulk(&_h_io_line_bulk_di, values) != 0)
		return -1;

	if (values[3]) *bitmap |= 1;
	if (values[4]) *bitmap |= 2;
	if (values[5]) *bitmap |= 4;
	if (values[6]) *bitmap |= 8;

	return true;
}

int _di_init()
{
	return
		(gpiod_chip_get_lines(_h_io_chip, _io_line_di_offsets, IRQ_PIN_COUNT, &_h_io_line_bulk_di) == 0)
		&& (gpiod_line_request_bulk_both_edges_events_flags(&_h_io_line_bulk_di, _IO_CONSUMER, GPIOD_LINE_REQUEST_FLAG_BIAS_PULL_UP) == 0);
}
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

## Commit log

2024-09-24 Added a 3D render of the complete PCB.
2024-09-24 First commit of the pcb.
    [BOM.xlsx, analog_inputs.kicad_sch, cog1.kicad_pcb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]
2024-09-24 First commit of the enclosure.
    [cog-1-back-lid.SLDPRT, cog-1-back-lid.STL, cog-1-front-lid.SLDPRT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]
2024-09-25 Added recommended threshold resistor and capacitor to all digital inputs, as recommended in the ISO1212 datasheet.
    [cog1.kicad_pcb, digital_inputs.kicad_sch]
2024-09-25 Minor changes in the digital outputs: changed 1K base resistors to 10K to save power. BC807 has an hfe of at least 100.
    [cog1.kicad_pcb, digital_outputs_sch.kicad_sch]
2024-09-25 Updated the BOM.
    [BOM.xlsx, cog1-bom.xlsx]
2024-09-27 Updated pcb and sent to prototype production as the first official version.
    [cog1.kicad_pcb, power_supply.kicad_sch]
2024-09-29 Reorganized the back-end and created the underlying framework.
2024-10-06 Minor adjustments in the fabrication layers to ease the manual soldering of components.
    [cog1.kicad_pcb]
2024-10-07 Updated picture of the newly-built official pcb.
2024-10-26 Improvements in the handling and storage of current variable values.
2024-11-09 Marked a resistor as "Do not mount" to improve RS-485 reception.
    [rs_485.kicad_sch]
2024-12-21 Small improvements to the design of the knob.
    [knob.SLDPRT, knob.STL]
2025-05-24 Simplified code auto-generation and other small fixes.
    [crc.xlsx]
2025-06-13 Finally solved the issue to reset the wifi driver when it doesn't reconnect.
2026-03-11 Minor adjustments to reflect the resistor values actually used in the board.
